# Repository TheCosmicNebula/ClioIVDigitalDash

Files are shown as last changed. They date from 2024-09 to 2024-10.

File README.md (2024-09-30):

 

# ClioIVDigitalDash
A place for me to store all my resources for my Renault Clio IV Digital Dash Project using RealDash, Raspberry Pi, Arduino and SocketCAN.

## License
All files are COPYRIGHT @ CGH Automotive Limited unless sourced from a Third Party, then the rights to those files are held with the relevant Third Party.

| 2023 - 2024 @ CGH Automotive Limited | TheCosmicNebula | All Rights Reserved (Except Where Specified) |

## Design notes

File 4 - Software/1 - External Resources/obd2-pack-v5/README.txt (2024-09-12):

Thanks for downloading our OBD2 data pack!

This pack contains the following:
1) Our OBD2 Intro & Data Logger articles in PDF form
2) Our OBD2 DBC file (for both 11-bit CAN IDs and 29-bit CAN IDs)
3) Various OBD2 sample log files - incl. an extensive one from a SEAT Leon
4) A collection of reverse-engineered DBC files, primarily from the opendbc github repo

You can open the MF4 log files e.g. in below software tools and use the OBD2 DBC to decode the data:

1) asammdf GUI: Good starting point for opening, DBC decoding and plotting the data
- Introduction: https://www.csselectronics.com/pages/asammdf-gui-api-mdf4-mf4

2) Python API: Automate the processing of the data
- Introduction: https://www.csselectronics.com/pages/python-can-bus-api

3) Grafana dashboards: Create custom dashboard visualizations of the data
- Introduction: https://www.csselectronics.com/pages/telematics-dashboard-open-source

4) MF4 converters: Ideal if you want to work with the log files in e.g. Vector/PEAK tools
- Introduction: https://www.csselectronics.com/pages/mdf4-converters-mf4-asc-csv

5) MF4 decoders: Easily DBC decode your data to CSV files or Parquet data lakes
- Introduction: https://www.csselectronics.com/pages/mdf4-decoders-dbc-mf4-parquet-csv

If any questions, feel free to contact us: https://www.csselectronics.com/pages/contact-us

best,
CSS Electronics

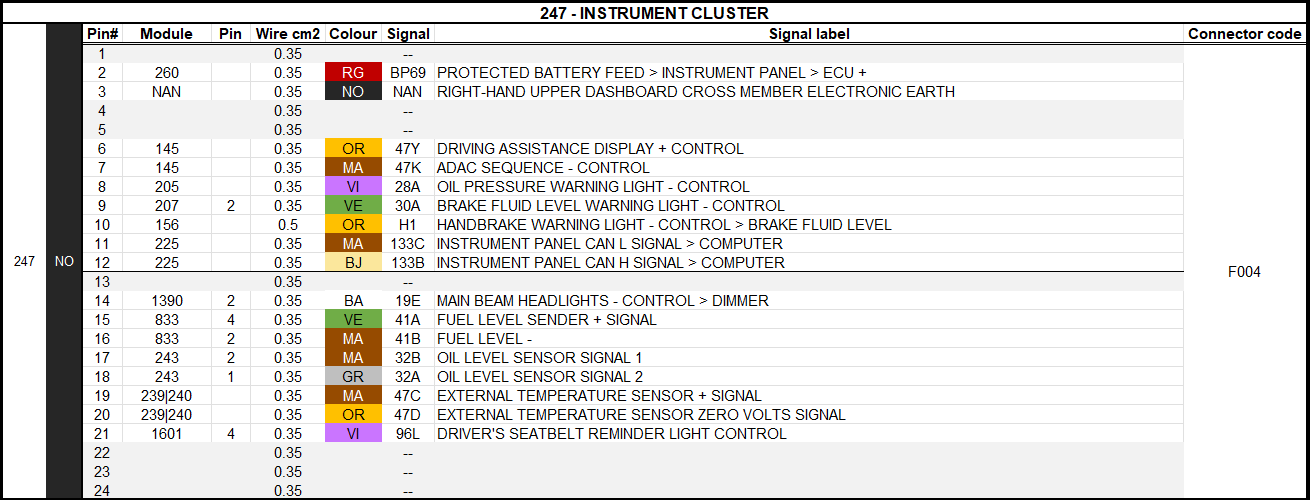
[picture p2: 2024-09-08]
1 - Physical Unit/2 - Connector/cluster_pinout_1.png

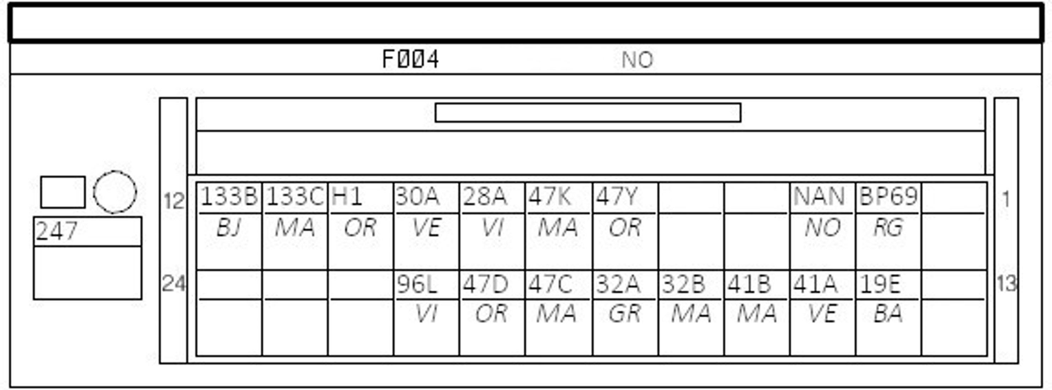
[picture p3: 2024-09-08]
1 - Physical Unit/2 - Connector/cluster_pinout.jpg

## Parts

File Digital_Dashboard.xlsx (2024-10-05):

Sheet: COST
 |  |  | £303.20 | £20.30 | £323.50
Item | Part # | Quantity | Cost | Delivery | Total | Status
10.4" QLED Quantum Dot Display |  | 1 | £104.10 | £9.99 | £114.09 | STORED
Raspberry Pi 5 |  | 1 | £52.00 |  | £52.00 | PROTOTYPE UNIT
RTC Battery for Raspberry Pi 5 |  | 1 | £4.90 | £10.31 | £15.21 | ORDERED
Waveshare RS485/CAN Hat |  | 1 | £16.99 |  | £16.99 | PROTOTYPE UNIT
Ardunio Nano Every |  | 1 | £13.95 |  | £13.95 | PROTOTYPE UNIT
12V to 5V 5A Buck Converter 2 pack |  | 1 | £6.97 |  | £6.97 | PROTOTYPE UNIT
Logitech K400 Plus Keyboard |  | 1 | £29.99 |  | £29.99 | PROTOTYPE UNIT
60mm 12V Cooling Fan |  | 1 | £4.86 |  | £4.86 | PROTOTYPE UNIT
OBD2 Connector Housing |  | 1 | £8.99 |  | £8.99 | PROTOTYPE UNIT
Copper Heatsinks for Raspberry Pi |  | 1 | £6.99 |  | £6.99 | PROTOTYPE UNIT
Single Channl 5V Relay Board x5 |  | 1 | £4.99 |  | £4.99 | PROTOTYPE UNIT
Right angle USB to Micro USB Cable |  | 1 | £3.00 |  | £3.00 | PROTOTYPE UNIT
Right angle USB to USB C cable |  | 1 | £6.99 |  | £6.99 | PROTOTYPE UNIT
USB C right angle extension |  | 1 | £7.49 |  | £7.49 | PROTOTYPE UNIT
Right angle HDMI to micro HDMI cable |  | 1 | £10.99 |  | £10.99 | PROTOTYPE UNIT
Shell |  | 1 | £20.00 |  | £20.00

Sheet: CLUSTER PINOUT
247 - INSTRUMENT CLUSTER
247 | NO | Pin# | Module | Pin | Size | Colour | Custom | Signal | Signal label
 |  | 1 |  |  | 0.35 |  |  | -- |  |  | F004
 |  | 2 | 260 |  | 0.35 | RG | RED | BP69 | PROTECTED BATTERY FEED > INSTRUMENT PANEL > ECU + | Power on all the time
 |  | 3 | NAN |  | 0.35 | NO | BLACK | NAN | RIGHT-HAND UPPER DASHBOARD CROSS MEMBER ELECTRONIC EARTH | Ground
 |  | 4 |  |  | 0.35 |  |  | --
 |  | 5 |  |  | 0.35 |  |  | --
 |  | 6 | 145 | 2 | 0.35 | OR | GREEN | 47Y | DRIVING ASSISTANCE DISPLAY + CONTROL | Stalk button upper, switch to ground
 |  | 7 | 145 | 3 | 0.35 | MA | BLUE | 47K | DRIVING ASSISTANCE DISPLAY - CONTROL | Stalk button lower, switch to ground
 |  | 8 | 205 |  | 0.35 | VI | YEL | 28A | OIL PRESSURE WARNING LIGHT - CONTROL | Ground NC - Low pressure = open circuit
 |  | 9 | 207 | 2 | 0.35 | VE | RED | 30A | BRAKE FLUID LEVEL WARNING LIGHT - CONTROL | Ground NO - Low brake fluid = closed circuit
 |  | 10 | 156 |  | 0.50 | OR | WHITE | H1 | HANDBRAKE WARNING LIGHT - CONTROL > BRAKE FLUID LEVEL | Ground NC - Handbrake on = closed circuit
 |  | 11 | 225 |  | 0.35 | MA | BLU | 133C | INSTRUMENT PANEL CAN L SIGNAL > COMPUTER | Main CANBus
 |  | 12 | 225 |  | 0.35 | BJ | YEL | 133B | INSTRUMENT PANEL CAN H SIGNAL > COMPUTER
 |  | 13 |  |  | 0.35 |  |  | --
 |  | 14 | 1390 | 2 | 0.35 | BA |  | 19E | MAIN BEAM HEADLIGHTS - CONTROL > DIMMER | Resistance based, brightness
 |  | 15 | 833 | 4 | 0.35 | VE | RED | 41A | FUEL LEVEL SENDER + SIGNAL | Resistance based
 |  | 16 | 833 | 2 | 0.35 | MA | GREEN | 41B | FUEL LEVEL -
 |  | 17 | 243 | 2 | 0.35 | MA |  | 32B | OIL LEVEL SENSOR SIGNAL - | Resistance based
 |  | 18 | 243 | 1 | 0.35 | GR |  | 32A | OIL LEVEL SENSOR SIGNAL +
 |  | 19 | 239|240 |  | 0.35 | MA | RED | 47C | EXTERNAL TEMPERATURE SENSOR + SIGNAL | Resistance based
 |  | 20 | 239|240 |  | 0.35 | OR | BLUE | 47D | EXTERNAL TEMPERATURE SENSOR ZERO VOLTS SIGNAL
 |  | 21 | 1601 | 4 | 0.35 | VI | WHITE | 96L | DRIVER'S SEATBELT REMINDER LIGHT CONTROL | Positive control
 |  | 22 |  |  | 0.35 |  |  | --
 |  | 23 |  |  | 0.35 |  |  | 133C | CAN L SIGNAL LOOP OUT
 |  | 24 |  |  | 0.35 |  |  | 133B | CAN H SIGNAL LOOP OUT

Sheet: PI PINOUT
Pinout |  |  |  |  |  | Pins needed |  |  | 13 | Function |  |  |  | 13
Used | Function | Pin |  | Function | Used | Function | Direction | Comments |  | Function | Pin | Used | Type |  | 3.3v
 | 3V3 Power | 1 | 2 | 5V Power |  | Oil Pressure Warning Light | IN | Via Arduino - Ground NC - Low pressure open circuit |  | 3V3 Power | 1 |  | 3.3v |  | 5v
 | GPIO 2 (SDA) | 3 | 4 | 5V Power |  | Brake Fluid Warning Light | IN | Via Arduino - Ground NO - Low brake fluid closed circuit |  | 5V Power | 2 |  | 5v |  | GND
 | GPIO 3 (SCL) | 5 | 6 | Ground |  | Handbrake Light | IN | Via Arduino - Ground NC - Handbrake on closed circuit |  | GPIO 2 (I2C_SDA) | 3 |  | I2C |  | I2C
CAN Hat | GPIO 4 (GPCLK0) | 7 | 8 | GPIO 14 (TXD) | CAN Hat | FUEL Level Sender + |  | Via Arduino |  | 5V Power | 4 |  | 5v |  | General
 | Ground | 9 | 10 | GPIO 15 (RXD) | CAN Hat | FUEL Level Sender - |  |  |  | GPIO 3 (I2C_SCL) | 5 |  | I2C |  | UART
FAN | GPIO 17 | 11 | 12 | GPIO 18 (PCM_CLK) |  | OIL Level Sender + |  | Via Arduino |  | Ground | 6 |  | GND |  | SPI
AIRBG | GPIO 27 | 13 | 14 | Ground |  | OIL Level Sender - |  |  |  | GPIO 4 (GPCLK0) | 7 | CAN Hat | General |  | PCM
 | GPIO 22 | 15 | 16 | GPIO 23 |  | External Temp + |  | Via Arduino |  | GPIO 14 (UART_TXD) | 8 | CAN Hat | UART
 | 3V3 Power | 17 | 18 | GPIO 24 |  | External Temp - |  |  |  | Ground | 9 |  | GND
CAN Hat | GPIO 10 (MOSI) | 19 | 20 | Ground |  | Stalk Button UP | IN | Via Arduino - Ground switched |  | GPIO 15 (UART_RXD) | 10 | CAN Hat | UART
CAN Hat | GPIO 9 (MISO) | 21 | 22 | GPIO 25 | CAN Hat | Stalk Button DOWN | IN | Via Arduino - Ground switched |  | GPIO 17 | 11 |  | General
CAN Hat | GPIO 11 (SCK) | 23 | 24 | GPIO 8 (CE0) | CAN Hat | Driver Airbag Light | OUT | Positive control |  | GPIO 18 (PCM_CLK) | 12 |  | PCM
 | Ground | 25 | 26 | GPIO 7 (CE1) |  | Onboard Fan Control | OUT | 5V Positive Controlled relay board |  | GPIO 27 | 13 |  | General
 | GPIO 0 (ID_SD) | 27 | 28 | GPIO 1 (ID_SC) |  |  |  |  |  | Ground | 14 |  | GND
 | GPIO 5 | 29 | 30 | Ground |  |  |  |  |  | GPIO 22 | 15 |  | General
 | GPIO 6 | 31 | 32 | GPIO 12 (PWM0) |  |  |  |  |  | GPIO 23 | 16 |  | General
 | GPIO 13 (PWM1) | 33 | 34 | Ground |  |  |  |  |  | 3V3 Power | 17 |  | 3.3v
 | GPIO 19 (PCM_FS) | 35 | 36 | GPIO 16 |  |  |  |  |  | GPIO 24 | 18 |  | General
 | GPIO 26 | 37 | 38 | GPIO 20 (PCM_DIN) |  |  |  |  |  | GPIO 10 (SPI0_MOSI) | 19 | CAN Hat | SPI
 | Ground | 39 | 40 | GPIO 21 (PDM_DOUT) |  |  |  |  |  | Ground | 20 |  | GND
 |  |  |  |  |  |  |  |  |  | GPIO 9 (SPI0_MISO) | 21 | CAN Hat | SPI
 |  |  |  |  |  | USB DEVICES |  |  |  | GPIO 25 | 22 | CAN Hat | General
 |  |  |  |  |  | USB 2.0 | LOGITECH KEYBOARD RECIEVER |  |  | GPIO 11 (SPI0_SCLK) | 23 | CAN Hat | SPI
 |  |  |  |  |  | USB 2.0 | GPS MODULE |  |  | GPIO 8 (CE0) | 24 | CAN Hat | SPI
 |  |  |  |  |  |  |  |  |  | Ground | 25 |  | GND
 |  |  |  |  |  | USB 3.0 | ARDUINO SERIAL CONNECTION |  |  | GPIO 7 (CE1) | 26 |  | SPI
 |  |  |  |  |  | USB 3.0 | WAVESHARE TOUCHSCREEN CONNECTION |  |  | GPIO 0 (EEPROM_SDA) | 27 |  | I2C
 |  |  |  |  |  |  |  |  |  | GPIO 1 (EEPROM_SCL) | 28 |  | I2C
 |  |  |  |  |  |  |  |  |  | GPIO 5 | 29 |  | General
 |  |  |  |  |  |  |  |  |  | Ground | 30 |  | GND
 |  |  |  |  |  |  |  |  |  | GPIO 6 | 31 |  | General
 |  |  |  |  |  |  |  |  |  | GPIO 12 (PWM0) | 32 |  | General
 |  |  |  |  |  |  |  |  |  | GPIO 13 (PWM1) | 33 |  | General
 |  |  |  |  |  |  |  |  |  | Ground | 34 |  | GND
 |  |  |  |  |  |  |  |  |  | GPIO 19 (PCM_FS) | 35 |  | PCM
 |  |  |  |  |  |  |  |  |  | GPIO 16 | 36 |  | General
 |  |  |  |  |  |  |  |  |  | GPIO 26 | 37 |  | General
 |  |  |  |  |  |  |  |  |  | GPIO 20 (PCM_DIN) | 38 |  | PCM
 |  |  |  |  |  |  |  |  |  | Ground | 39 |  | GND
 |  |  |  |  |  |  |  |  |  | GPIO 21 (PDM_DOUT) | 40 |  | PCM

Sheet: ARDUINO PINOUT
Pinout |  |  |  |  |  |  |  | Pins needed
Used |  |  |  | Pin |  |  | Used | Function | DIR | Comments
LED_BUILTIN |  |  |  | D13 | D12 | INT_PULLUP | STALK+ | Oil Pressure Warning Light | IN | Ground NC - Normal pressure grounded, Low Pressure 5V
 |  |  |  | 3V3 | D11 | INT_PULLUP | STALK- | Brake Fluid Warning Light | IN | Ground NO - Low brake fluid gounded
 |  |  |  | AREF | D10 |  | PWM | Handbrake Light | IN | Ground NC - Handbrake activated grounded
DIMMER | DIVIDER | 14.5V -> 5V | A0 | D14 | D9 |  | PWM | FUEL Level Sender + | PWR | 5V Supply with 2K Voltage Divider
FUEL LEVEL | DIVIDER 2K | 5V | A1 | D15 | D8 | INT_PULLUP | OIL PRESS | FUEL Level Sender - | IN
EXT TEMP | DIVIDER 2K | 5V | A2 | D16 | D7 | INT_PULLUP | BRAKE FLUID | OIL Level Sender + | PWR | 5V Supply with 2K Voltage Divider
OIL LEVEL | DIVIDER 2K | 5V | A3 | D17 | D6 |  | PWM | OIL Level Sender - | IN
 |  |  | A4 | D18 | D5 |  | PWM | External Temp + | PWR | 5V Supply with 2K Voltage Divider
 |  |  | A5 | D19 | D4 | INT_PULLUP | HANDBRAKE | External Temp - | IN
 |  |  | A6 | D20 | D3 |  | PWM | Stalk Button UP | IN | Grounded when pressed
 |  |  | A7 | D21 | D2 |  |  | Stalk Button DOWN | IN | Grounded when pressed
 |  |  |  | +5V | GND |  |  | DIMMER | IN | 12 - 15V assumed variable voltage
 |  |  |  | RST | RST
 |  |  |  | GND | TX
7 - 21V |  | 7 - 21V |  | VIN | RX
2K divider needs verifying that 2K is suitable
DIMMER is 12v (14.5)v LPE or Internal Lighting Activated with a Variable Potentiometer
Measure resistance and use minimum and maximum to determine suitable voltage divider setup
 |  |  |  |  | 1 | OIL SIG
 |  |  |  |  | 2 | OIL +
 |  |  |  |  | 3 | TEMP SIG
 |  |  |  |  | 4 | TEMP +
 |  |  |  |  | 5 | FUEL SIG
 |  |  |  |  | 6 | FUEL +

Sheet: FUNCTIONS
 |  |  |  |  |  |  | -
Function List (Not Exhaustive) |  |  |  |  |  |  | ✔
No | Function | Desc | OBD2 | CanBUS | NANO | CanAddress | ✖
 | Cluster Lights
1 | Left Indicator |  |  | ✔
2 | Right Indicator |  |  | ✔ |  |  |  | CAN Wake Up Signal
3 | Hazard Indicators |  |  | ✔ |  |  |  | CAN Sleep Signal
4 | Battery Warning |  |  |  |  |  |  | OR
5 | Main Beam |  |  | ✔ |  |  |  | Use accessory power for wake, or other protected power source that is on before accessory and after accessory, but does not drain battery
6 | Low Beam |  |  | ✔
7 | Side Lights |  |  | ✔
8 | Cruise Control |  |  | ✔
9 | Speed Limiter |  |  | ✔ |  |  |  | Turn off Pi boot screen | in | /boot/firmware/config.txt
10 | Handbrake ON |  |  | - | ✔ | Arduino Nano via CAN |  |  |  | + disable_splash=1
11 | ESC Off |  |  | ✔ |  |  |  |  |  | +logo.nologo
12 | STOP |  |  |  |  |  |  |  |  | +consoleblank=0
13 | Door Open |  |  | ✔ |  |  |  |  |  | +loglevel=1 quiet | didnt work
14 | OSF Door Open |  |  | ✔
15 | NSF Door Open |  |  | ✔
16 | OSR Door Open |  |  | ✔
17 | NSR Door Open |  |  | ✔
18 | Boot Open |  |  | ✔
19 | SPANNER
20 | Temp Low |  |  | ✔
21 | Temp High |  |  | ✔ |  |  |  | /home/pi/startup.py |  | Fan on + drivers airbag light for 1 minute
22 | Oil Warning |  |  | - | ✔ | Arduino Nano via CAN |  | /home/pi/stop_fan.py
23 | Fuel Low |  |  | - | ✔ | Arduino Nano via CAN
24 | Tyre Pressure
25 | ABS |  |  | ✔
26 | Front Fog |  |  | ✔
27 | Rear Fog |  |  | ✔
28 | Check Engine |  |  | ✔
29 | Airbag |  |  | ✔
30 | Renaultsport |  |  | ✔
 | Cluster Messages
1 | PARKING BRAKE ON |  |  | ✔
2 | PLEASE REMOVE KEYCARD
3 | TRACTION CONTROL OFF
4 | ESC OFF |  |  | ✔
5 | TURN STEERINGWHEEL + START
6 | STEERING WHEEL NOT LOCKED
7 | CHECK VEHICLE
8 | CHECK AIRBAG
9 | CHECK ANTI-POLLUTION SYSTEM
10 | CHECK HILL START ASSIST
11 | ENGINE FAILURE HAZARD
12 | BRAKING SYSTEM FAULT
13 | BATTERY CHARGING FAULT
14 | PUNCTURE
15 | LAUNCH CONTROL
16
17
 | Cluster Info
1 | Speed |  | ✖ | ✔
2 | Rpm |  | ✔ | ✔
3 | Fuel Level |  | ✖ | - | ✔ | Arduino Nano via CAN
4 | Handbrake |  | ✔ | - | ✔ | Arduino Nano via CAN | CanBUS is transmitted by OEM cluster so this will be lost when full swap is done
5 | Current Gear |  | ✖ | ✔
6 | Auto / Manual |  | ✖ | ✔
7 | Gear Change Up |  | ✖
8 | Gear Change Down |  | ✖
9 | SPORT Mode |  | ✔ | ✔
10 | RACE Mode |  | ✔ | ✔
11 | Oil Level Warning |  | ✖ | - | ✔ | Arduino Nano via CAN
12 | Oil Pressure Warning |  | ✖ | - | ✔ | Arduino Nano via CAN
13 | External Temperature |  | ✖ | - | ✔ | Arduino Nano via CAN
14 | Mileage / Odometer |  | ✖ | ✔
15 | Battery Voltage
 | front right belt
 | front left belt
 | rear right belt
 | rear centre belt
 | rear left belt
 | Airbag Light
 | passenger seat detection
 | parking sensor info
 | gear up indicator
 | gear down indicator
 | check 666 for traction control |  | 666
 | boot |  | 5DE
 | Traction control off
 | key in slot
 | windows up / down
 | interior light?

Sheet: REALDASH
Function | Type | Number | Units
AFR 1 |  | 0 | C
AFR 2 |  | 1 | F
AFR Target 1 |  | 2 | K
AFR Target 2 |  | 3 | km/h
Accel Enrich |  | 4 | mph
Barometric Correction |  | 10 | bar
Barometric Pressure |  | 11 | psi
Battery Voltage |  | 12 | time
Boost Target (kPa) |  | 270 | bit
Check Engine Light | ON/OFF | 65
Cold Advance |  | 13
Coolant Temperature | Celsius | 14
EGO Correction 1 |  | 17
EGO Correction 2 |  | 18
EGT1 | Celsius | 106
EGT10 | Celsius | 115
EGT11 | Celsius | 116
EGT12 | Celsius | 117
EGT2 | Celsius | 107
EGT3 | Celsius | 108
EGT4 | Celsius | 109
EGT5 | Celsius | 110
EGT6 | Celsius | 111
EGT7 | Celsius | 112
EGT8 | Celsius | 113
EGT9 | Celsius | 114
Engine Oil Pressure | Bar | 151
Engine Oil Temperature | Celsius | 152
Engine Runtime (sec) |  | 33
Enginebit: Antiflood | ON/OFF | 393
Enginebit: Closed Loop Active | ON/OFF | 395
Enginebit: Cranking | ON/OFF | 57
Enginebit: Fuel Cut Active |  | 406
Enginebit: Idle | ON/OFF | 396
Enginebit: Launch Control | ON/OFF | 394
Enginebit: MAP accel active | ON/OFF | 62
Enginebit: MAP deaccel active | ON/OFF | 63
Enginebit: Overrun | ON/OFF | 397
Enginebit: Running | ON/OFF | 56
Enginebit: Startup Enrich | ON/OFF | 58
Enginebit: TPS accel active | ON/OFF | 60
Enginebit: TPS deaccel active | ON/OFF | 61
Enginebit: Warmup | ON/OFF | 59
Flex Fuel Correction |  | 20
Fuel Pressure | Bar | 202
Fuel Temperature | Celsius | 499
Fuel flow |  | 490
Ignition Dwell |  | 26
Intake Air Temperature | Celsius | 27
Knock Advance Retard |  | 28
Knock Percentage |  | 29
Lambda 1 |  | 254
Lambda 2 |  | 255
Lambda Target 1 |  | 256
Lambda Target 2 |  | 257
MAF g/s |  | 30
Manifold Absolute Pressure |  | 31
Manifold Absolute Pressure dot |  | 32
Number of CEL codes |  | 66
OBD2: Engine Load |  | 100
OBD2: Long Term Fuel Trim, Bank 1 |  | 102
OBD2: Long Term Fuel Trim, Bank 2 |  | 104
OBD2: Short Term Fuel Trim, Bank 1 |  | 101
OBD2: Short Term Fuel Trim, Bank 2 |  | 103
Pulse Width 1 |  | 35
Pulse Width 2 |  | 36
RPM |  | 37
Rotating Error Code |  | 105
Spark Advance |  | 38
TPS dot |  | 41
Throttle Position |  | 41
Total Fuel Correction |  | 43
VSS1 | KPH | 81
VSS2 | KPH | 99
VVT, Exhaust Cam Position 1 |  | 493
VVT, Exhaust Cam Position 2 |  | 495
VVT, Exhaust Cam Target Position |  | 497
VVT, Intake Cam Position 1 |  | 492
VVT, Intake Cam Position 2 |  | 494
VVT, Intake Cam Target Position |  | 496
Vehicle Max Speed | KPH | 408
Vehicle Speed | KPH | 64
2nd Gear Start indicator (Transmission) | ON/OFF | 148
4WD Active | ON/OFF | 149
4WD Low Range Active | ON/OFF | 150
Downshift indicator (Transmission) | ON/OFF | 145
Gear (Transmission) |  | 139
Lockup Active (Transmission) | ON/OFF | 143
Low Range indicator (Transmission) | ON/OFF | 146
Oil Temperature (Transmission) | ON/OFF | 138
Overdrive indicator (Transmission) | ON/OFF | 147
Selected Gear (Transmission) |  | 140
Shifter Position (Transmission) |  | 141
Throttle Position (Transmission) |  | 137
Tuning Map (Transmission) |  | 142
Upshift indicator (Transmission) | ON/OFF | 144
Vehicle Speed (Transmission) | KPH | 136
ABS Warning |  | 273
AC Active |  | 335
AC Set Temperature (Zone 1) |  | 175
AC Set Temperature (Zone 2) |  | 312
AC Set Temperature (Zone 3) |  | 313
AC Set Temperature (Zone 4) |  | 314
Air Flow Defrost Active (Zone 1) | ON/OFF | 315
Air Flow Defrost Active (Zone 2) | ON/OFF | 318
Air Flow Defrost Active (Zone 3) | ON/OFF | 321
Air Flow Defrost Active (Zone 4) | ON/OFF | 324
Air Flow Face Active (Zone 1) | ON/OFF | 317
Air Flow Face Active (Zone 2) | ON/OFF | 320
Air Flow Face Active (Zone 3) | ON/OFF | 323
Air Flow Face Active (Zone 4) | ON/OFF | 326
Air Flow Feet Active (Zone 1) | ON/OFF | 316
Air Flow Feet Active (Zone 2) | ON/OFF | 319
Air Flow Feet Active (Zone 3) | ON/OFF | 322
Air Flow Feet Active (Zone 4) | ON/OFF | 325
Air Recirculation Active | ON/OFF | 336
Airbag Warning | ON/OFF | 272
Ambient Temperature | Celsius | 173
Brake Fluid Level |  | 178
Brake LF temperature | Celsius | 244
Brake LR temperature | Celsius | 246
Brake RF temperature | Celsius | 245
Brake RR temperature | Celsius | 247
Brake pedal position |  | 230
Clutch pedal position |  | 231
Coolant Level |  | 177
Cruise Control Accelerate | ON/OFF | 735
Cruise Control Active | ON/OFF | 169
Cruise Control Autospeed Active | ON/OFF | 737
Cruise Control Decelerate | ON/OFF | 736
Cruise Control Set Value | KPH | 171
Distance to ObstacleKilometers | Kilometers | 354
Door 1 Open | ON/OFF | 481
Door 2 Open | ON/OFF | 482
Door 3 Open | ON/OFF | 483
Door 4 Open | ON/OFF | 484
Door 5 Open | ON/OFF | 485
Door 6 Open | ON/OFF | 486
Door Ajar | ON/OFF | 162
EV: Battery Charge Time |  | 341
EV: Battery Charge Time Remaining |  | 342
EV: Battery Level 1 |  | 478
EV: Battery Level 2 |  | 479
EV: Battery Voltage |  | 339
EV: Charge Voltage |  | 340
EV: Energy Consumption (W/hr) |  | 337
EV: Energy Consumption Average (Wh/distance) |  | 338
Engine Cooling Fan | ON/OFF | 153
Engine Oil Level |  | 180
Front Fog Lights | ON/OFF | 392
Fuel Level |  | 170
Fuel Pump 1 | ON/OFF | 182
Fuel Pump 2 | ON/OFF | 183
Fuel Pump 3 | ON/OFF | 184
Fuel Pump 4 | ON/OFF | 185
Gear |  | 200
Hazard Switch | ON/OFF | 166
Heater Motor Level |  | 172
High Beam | ON/OFF | 157
Hood Open | ON/OFF | 487
Horn | ON/OFF | 165
Ignition On | ON/OFF | 167
Inside Temperature |  | 174
Instrument Panel Lights | ON/OFF | 186
Interior Lights | ON/OFF | 187
Low Beam | ON/OFF | 156
Neutral Safety Switch | ON/OFF | 489
Odometer | Kilometers | 310
Parking Brake | ON/OFF | 164
Parking Lights | ON/OFF | 155
Rear Fog Lights | ON/OFF | 158
Reverse Lights | ON/OFF | 159
Seat Belt Warning | ON/OFF | 168
Seat Cooler (Zone 1) |  | 331
Seat Cooler (Zone 2) |  | 332
Seat Cooler (Zone 3) |  | 333
Seat Cooler (Zone 4) |  | 334
Seat Heater (Zone 1) |  | 327
Seat Heater (Zone 2) |  | 328
Seat Heater (Zone 3) |  | 329
Seat Heater (Zone 4) |  | 330
Starter Motor | ON/OFF | 154
Steering Wheel 1 | ON/OFF | 188
Steering Wheel 2 | ON/OFF | 189
Steering Wheel 3 | ON/OFF | 190
Steering Wheel 4 | ON/OFF | 191
Steering Wheel 5 | ON/OFF | 192
Steering Wheel 6 | ON/OFF | 193
Steering Wheel Angle (degrees) |  | 229
Steering Wheel DPAD Back | ON/OFF | 199
Steering Wheel DPAD Down | ON/OFF | 197
Steering Wheel DPAD Left | ON/OFF | 194
Steering Wheel DPAD OK | ON/OFF | 198
Steering Wheel DPAD Right | ON/OFF | 196
Steering Wheel DPAD Up | ON/OFF | 195
Traction Control Percentage |  | 179
Tripmeter A | Kilometers | 311
Tripmeter B | Kilometers | 356
Trunk Ajar | ON/OFF | 163
Turn Signal Left | ON/OFF | 160
Turn Signal Right | ON/OFF | 161
Tyre Front Left Battery Low | ON/OFF | 743
Tyre Front Left Leaking | ON/OFF | 739
Tyre Front Left Pressure | Bar | 240
Tyre Front Left Sensor Connected | ON/OFF | 747
Tyre Front Left Temperature | Celsius | 232
Tyre Front Left Wear |  | 236
Tyre Front Right Battery Low | ON/OFF | 744
Tyre Front Right Leaking | ON/OFF | 740
Tyre Front Right Pressure | Bar | 241
Tyre Front Right Sensor Connected | ON/OFF | 748
Tyre Front Right Temperature | Celsius | 233
Tyre Front Right Wear |  | 237
Tyre Rear Left Battery Low | ON/OFF | 745
Tyre Rear Left Leaking | ON/OFF | 741
Tyre Rear Left Pressure | Bar | 242
Tyre Rear Left Sensor Connected | ON/OFF | 479
Tyre Rear Left Temperature | Celsius | 234
Tyre Rear Left Wear |  | 238
Tyre Rear Right Battery Low | ON/OFF | 746
Tyre Rear Right Leaking | ON/OFF | 742
Tyre Rear Right Pressure | Bar | 243
Tyre Rear Right Sensor Connected | ON/OFF | 758
Tyre Rear Right Temperature | Celsius | 235
Tyre Rear Right Wear |  | 239
Washer Fluid Level |  | 176
Windshield Washer Active | ON/OFF | 181
Acceleration (ABS) |  | 5
Acceleration X |  | 6
Acceleration X (RAW) |  | 264
Acceleration Y |  | 7
Acceleration Y (RAW) |  | 265
Acceleration Z |  | 8
Acceleration Z (RAW) |  | 266
Audio Volume |  | 275
Battery Charging | ON/OFF | 343
Battery Level |  | 253
Bluetooth Active |  | 276
Connected Device Count |  | 365
Date | Text | 211
GPS AltitudeMeters | Meters | 21
GPS Connected | ON/OFF | 252
GPS Date | Text | 358
GPS Heading |  | 209
GPS Latitude |  | 22
GPS Longitude |  | 23
GPS Speed | KPH | 24
GPS Time | Text | 357
Heart Rate |  | 250
Keyboard Status |  | 498
Navigation: Active | ON/OFF | 344
Navigation: Distance to Destination | Kilometers | 346
Navigation: Distance to next Waypoint | Kilometers | 347
Navigation: ETA | Text | 350
Navigation: Instruction, Current | Text | 348
Navigation: Instruction, Next | Text | 349
Navigation: Maneuver, Current | Text | 351
Navigation: Maneuver, Next 1 | Text | 352
Navigation: Maneuver, Next 2 | Text | 353
Navigation: Time to Destination |  | 345
Night Mode |  | 309
Screen Brightness |  | 274
Screen Capture Active | ON/OFF | 491
System Notification | Text | 248
Time (ISO 8601) | Text | 118
Time (Local) | Text | 210
Weekday | Text | 359
WiFi Active |  | 277
App ShutdownOn/Off87 | ON/OFF | 87
App Started |  | 86
Color Brightness Slider |  | 376
Color Slider 1 |  | 366
Color Slider 2 |  | 367
Color Slider 3 |  | 368
Color Slider 4 |  | 369
Current Dash Page |  | 404
Currently Playing Album | Text | 89
Currently Playing Artist | Text | 88
Currently Playing Duration |  | 278
Currently Playing Folder | Text | 488
Currently Playing Position |  | 279
Currently Playing Title | Text | 90
Dummy 01 |  | 93
Dummy 02 |  | 94
Dummy 03 |  | 95
Dummy 04 |  | 96
Dummy 05 |  | 97
Dummy 06 |  | 121
Dummy 07 |  | 122
Dummy 08 |  | 123
Dummy 09 |  | 124
Dummy 10 |  | 125
Dummy 11 |  | 126
Dummy 12 |  | 127
Dummy 13 |  | 128
Dummy 14 |  | 129
Dummy 15 |  | 130
Dummy 16 |  | 131
Dummy 17 |  | 132
Dummy 18 |  | 133
Dummy 19 |  | 134
Dummy 20 |  | 135
Dummy 21 |  | 281
Dummy 22 |  | 282
Dummy 23 |  | 283
Dummy 24 |  | 284
Dummy 25 |  | 285
Dummy 26 |  | 286
Dummy 27 |  | 287
Dummy 28 |  | 288
Dummy 29 |  | 289
Dummy 30 |  | 290
Dummy 31 |  | 291
Dummy 32 |  | 292
Dummy 33 |  | 293
Dummy 34 |  | 294
Dummy 35 |  | 295
Dummy 36 |  | 296
Dummy 37 |  | 297
Dummy 38 |  | 298
Dummy 39 |  | 299
Dummy 40 |  | 301
Dummy timer 01 |  | 34
Dummy timer 02 |  | 47
Dummy timer 03 |  | 48
Dummy timer 04 |  | 49
Dummy timer 05 |  | 98
Dummy timer 06 |  | 302
Dummy timer 07 |  | 303
Dummy timer 08 |  | 304
Dummy timer 09 |  | 305
Dummy timer 10 |  | 306
Heading as text | Text | 362
Map Center Latitude |  | 307
Map Center Longitude |  | 308
Map Zoom Level |  | 280
RealDash language codeText361 | Text | 361
Song Playing |  | 360
Song playback shuffle active |  | 405
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

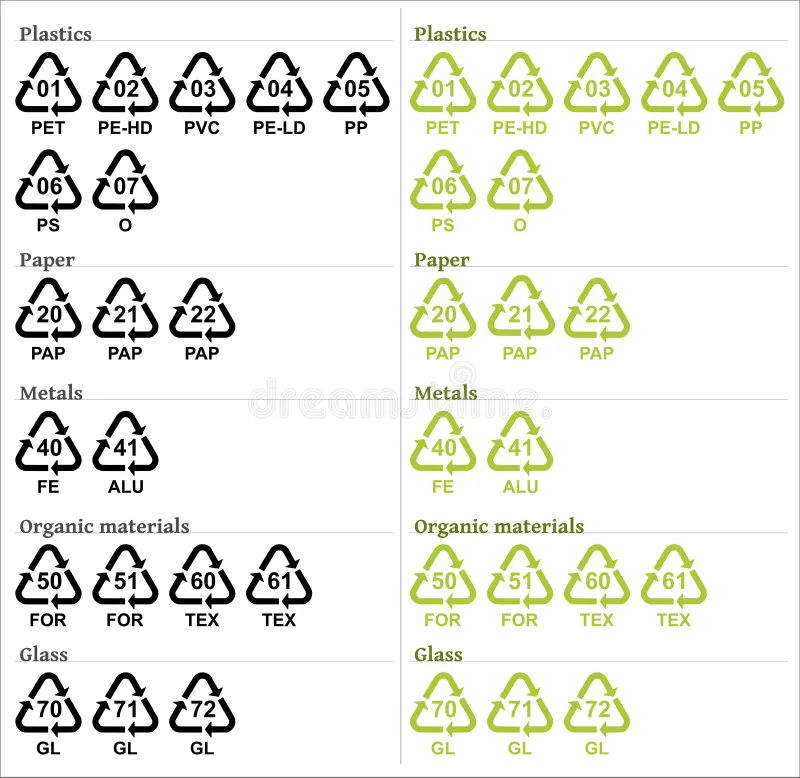
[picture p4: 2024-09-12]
1 - Physical Unit/3 - Label/components/recycle-symbols-codes-23069352.webp

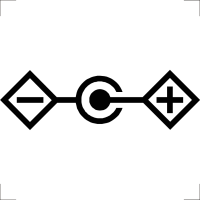
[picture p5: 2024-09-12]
1 - Physical Unit/3 - Label/components/polarity.png

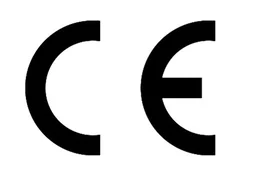
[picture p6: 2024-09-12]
1 - Physical Unit/3 - Label/components/CE-mark.webp

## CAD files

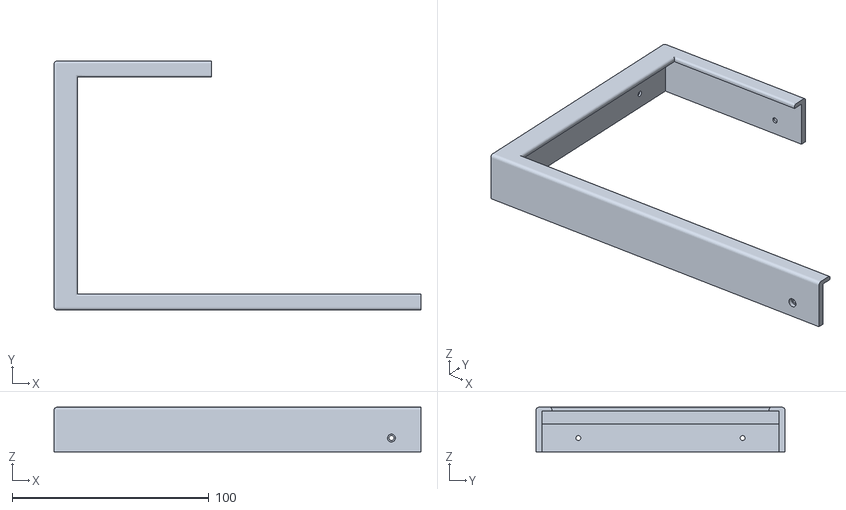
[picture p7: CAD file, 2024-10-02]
1 - Physical Unit/0 - Casing/bezel_left_v4.stl
186.3 x 126.4 x 22.7

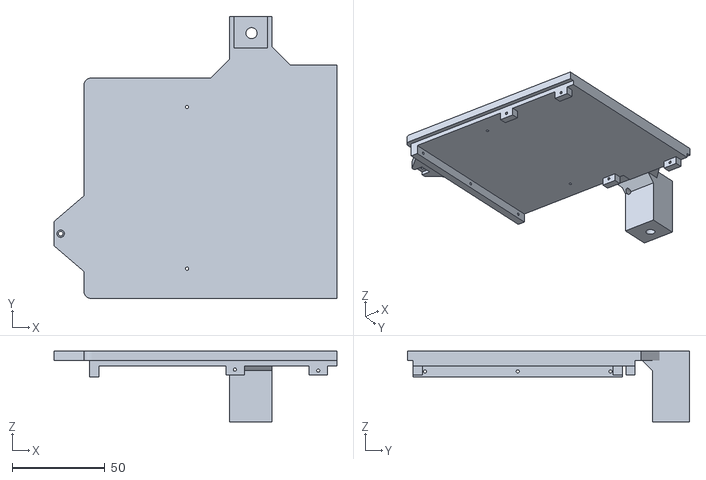
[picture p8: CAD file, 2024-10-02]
1 - Physical Unit/0 - Casing/ss/plate_left_v12.stl
152.5 x 152.2 x 38.2

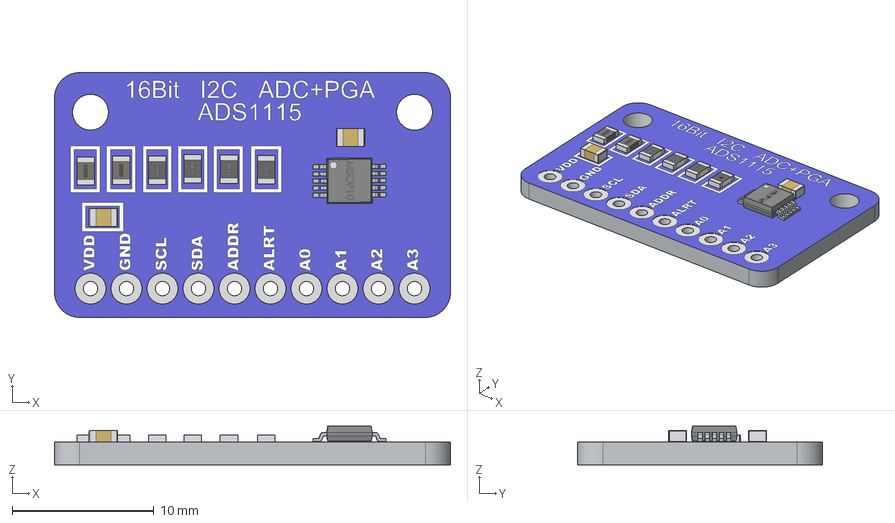
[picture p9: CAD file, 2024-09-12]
1 - Physical Unit/1 - Pi/ADCs/16Bit I2C ADC+PGA - ADS1115.stp
27.9 x 17.3 x 2.74 mm
ADS1115
0805 Capacitor x 2
0805 Inductor x 2
0805 Resistor x 4
MSOP10

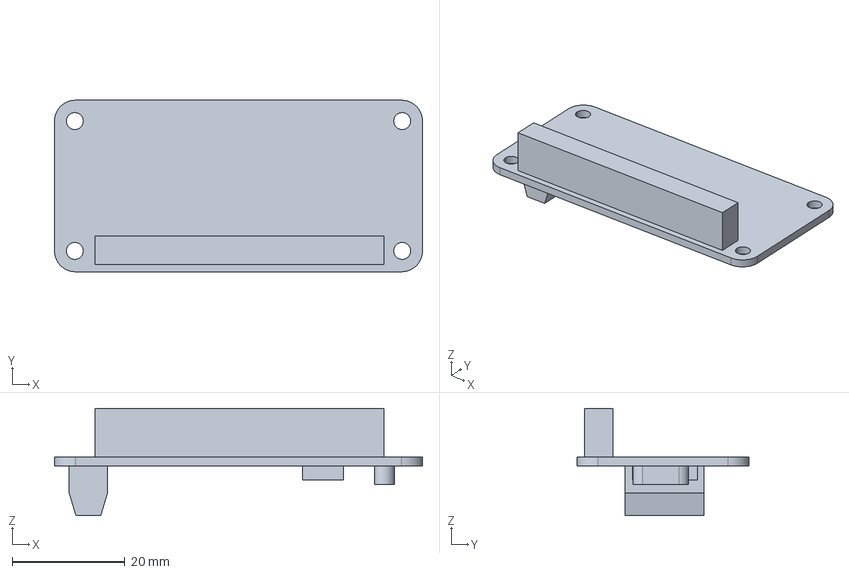
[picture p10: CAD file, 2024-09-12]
1 - Physical Unit/1 - Pi/CAN_Hat/t19-3.stp
65.2 x 30.4 x 19.0 mm

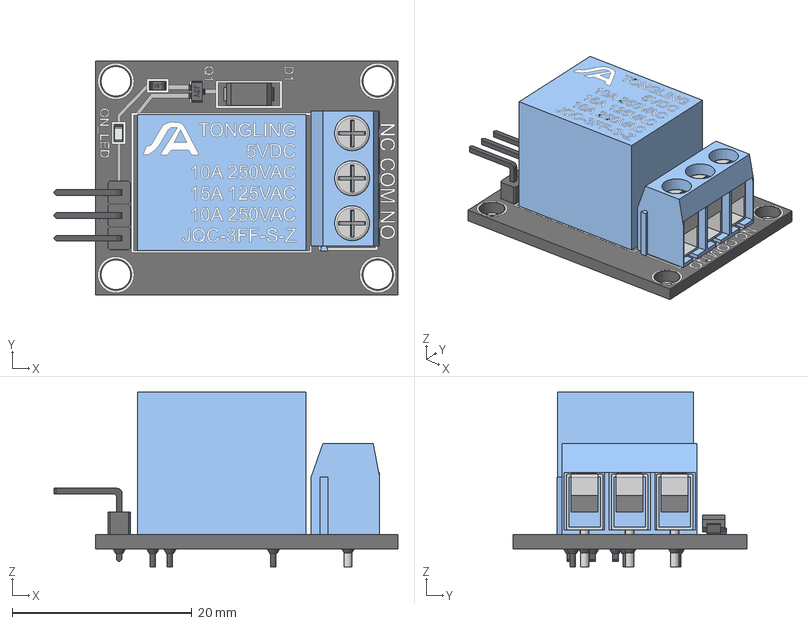
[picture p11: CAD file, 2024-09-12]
1 - Physical Unit/1 - Pi/Relay Board/5V KY-019 v95.step
38.2 x 26.0 x 19.4 mm
Tornillo M3X15 x 3
Pin_interno x 3
Punto se soldadura x 11
Relevador 5VDC
Diodo M7
LED VERDE SMD
RESISTENCIA 151
Transistor
Header_Body x 3
Pin x 3

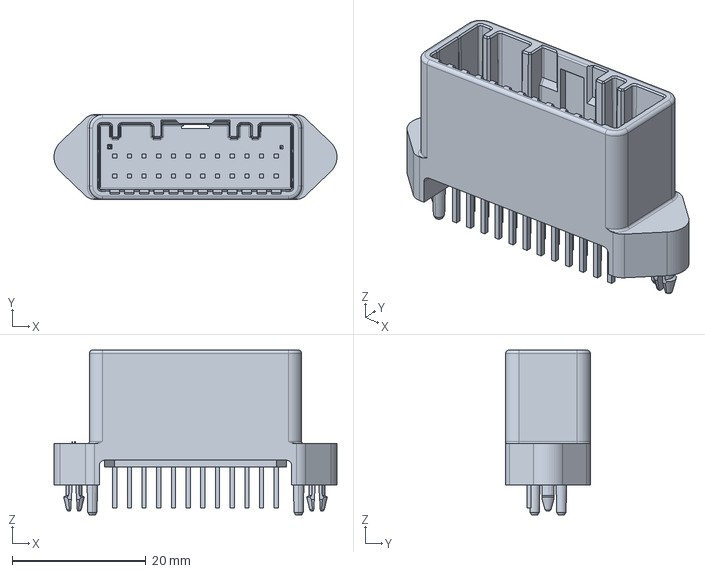
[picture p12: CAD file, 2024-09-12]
1 - Physical Unit/2 - Connector/1802828-1/c-1802828-1-a-3d.stp
42.4 x 12.7 x 24.7 mm

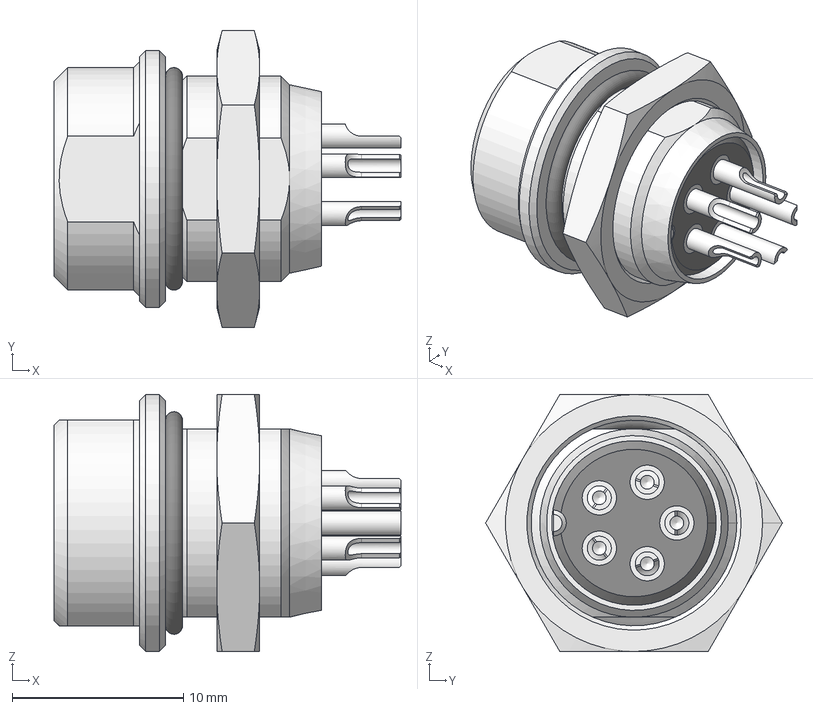
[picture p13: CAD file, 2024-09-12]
1 - Physical Unit/9 - Prototype/components/GX12-5 Jack.step
20.2 x 17.3 x 15.0 mm

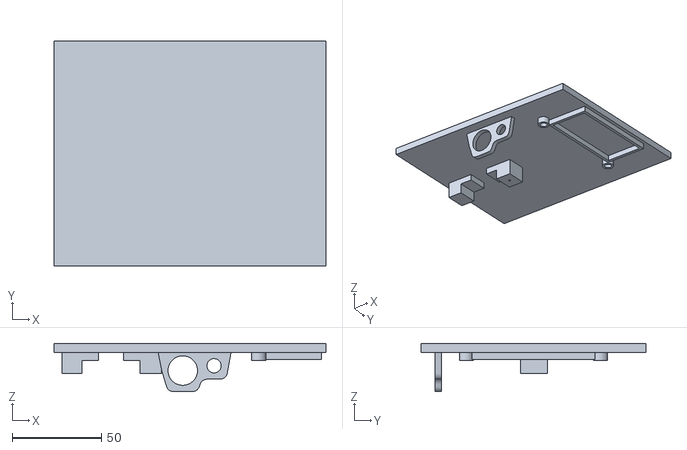
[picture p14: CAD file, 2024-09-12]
1 - Physical Unit/9 - Prototype/rear_plate_left_v2.stl
152.0 x 126.0 x 26.9

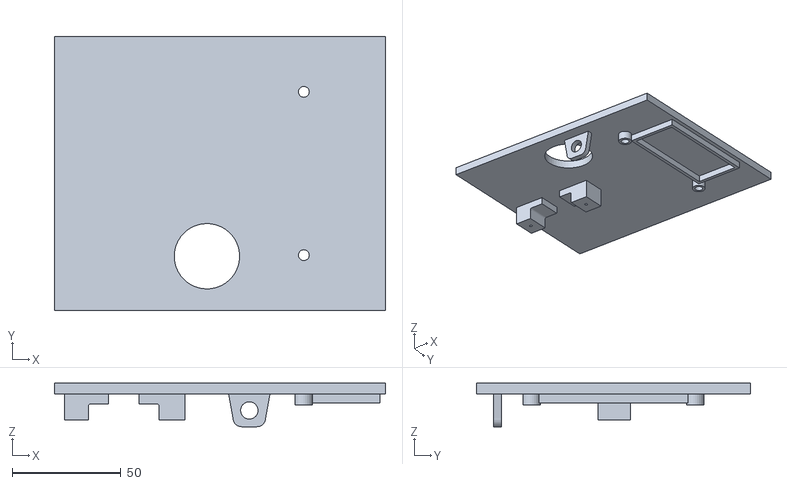
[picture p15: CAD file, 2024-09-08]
1 - Physical Unit/9 - Prototype/ss/rear_plate_left_v1.stl
152.0 x 126.0 x 20.0

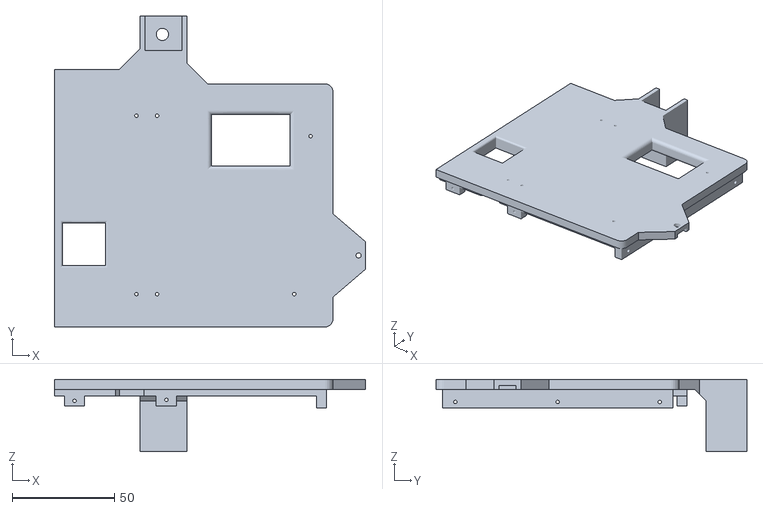
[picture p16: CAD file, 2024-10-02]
1 - Physical Unit/0 - Casing/plate_right_v14.stl
152.4 x 152.2 x 35.2

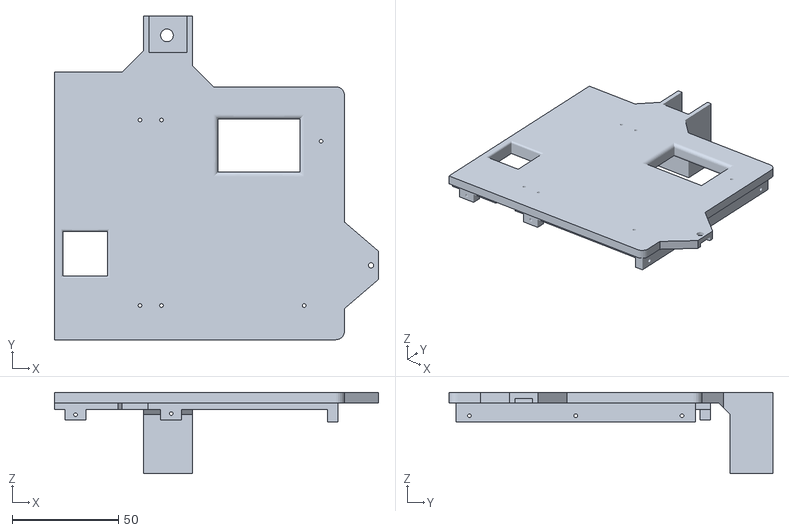
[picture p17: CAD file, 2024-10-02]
1 - Physical Unit/0 - Casing/ss/plate_right_v13.stl
152.4 x 152.2 x 38.2

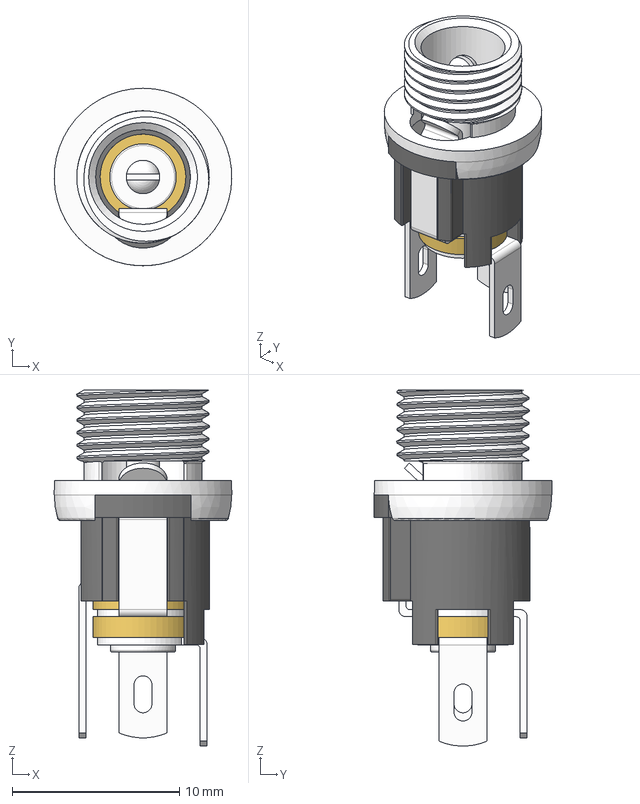
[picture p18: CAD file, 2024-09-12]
1 - Physical Unit/9 - Prototype/components/panel mount 5.5 x 2.1mm barrel plug.step
10.6 x 10.6 x 21.3 mm
Casing
insulators
Positive Center
Negative parts

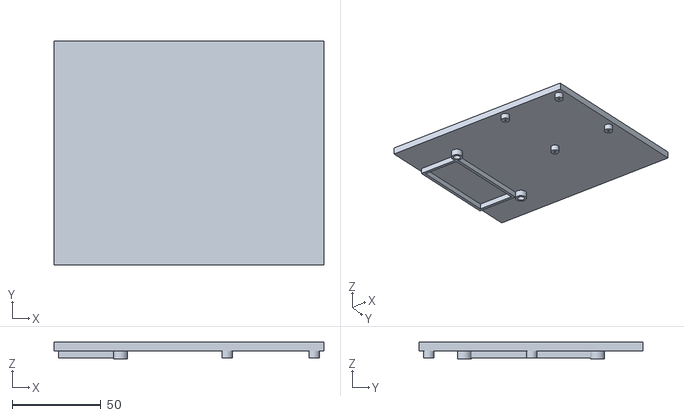
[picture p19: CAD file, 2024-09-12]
1 - Physical Unit/9 - Prototype/rear_plate_right_v2.stl
152.0 x 126.0 x 9.50

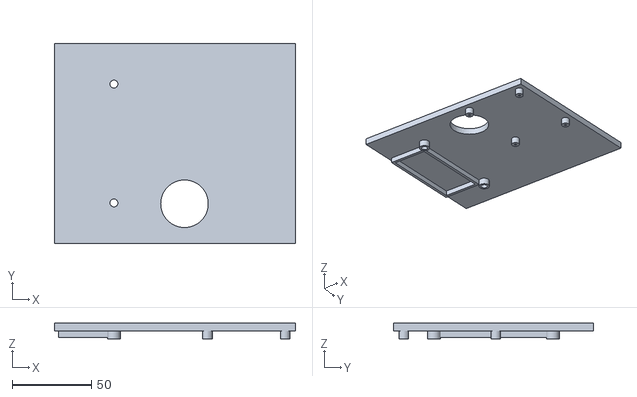
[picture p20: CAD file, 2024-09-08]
1 - Physical Unit/9 - Prototype/ss/rear_plate_right_v1.stl
152.0 x 126.0 x 10.0

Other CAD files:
1 - Physical Unit/0 - Casing/bezel_right_v4.stl
1 - Physical Unit/0 - Casing/ss/temp_bezel_left_1.stl
1 - Physical Unit/9 - Prototype/connector_clamp.stl
1 - Physical Unit/9 - Prototype/ss/rear_plate_v1.stl
1 - Physical Unit/0 - Casing/back_cover_left_v4.stl
1 - Physical Unit/0 - Casing/back_cover_right_v4.stl
1 - Physical Unit/0 - Casing/connector_retention_v4.stl
1 - Physical Unit/0 - Casing/fan_duct_v3.stl
1 - Physical Unit/0 - Casing/frame_clamp_v1.stl
1 - Physical Unit/0 - Casing/frame_left_v1.stl
1 - Physical Unit/0 - Casing/frame_right_bottom_v1.stl
1 - Physical Unit/0 - Casing/frame_right_top_v1.stl
1 - Physical Unit/0 - Casing/pin_v2.stl
1 - Physical Unit/0 - Casing/plate_left_v14.stl
1 - Physical Unit/0 - Casing/rear_shell_left_v9.stl
1 - Physical Unit/0 - Casing/rear_shell_right_v9.stl
1 - Physical Unit/0 - Casing/ss/back_cover_left_v1.stl
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

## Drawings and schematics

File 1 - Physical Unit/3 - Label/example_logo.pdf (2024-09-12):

109.6+/-0.1
3 | 3

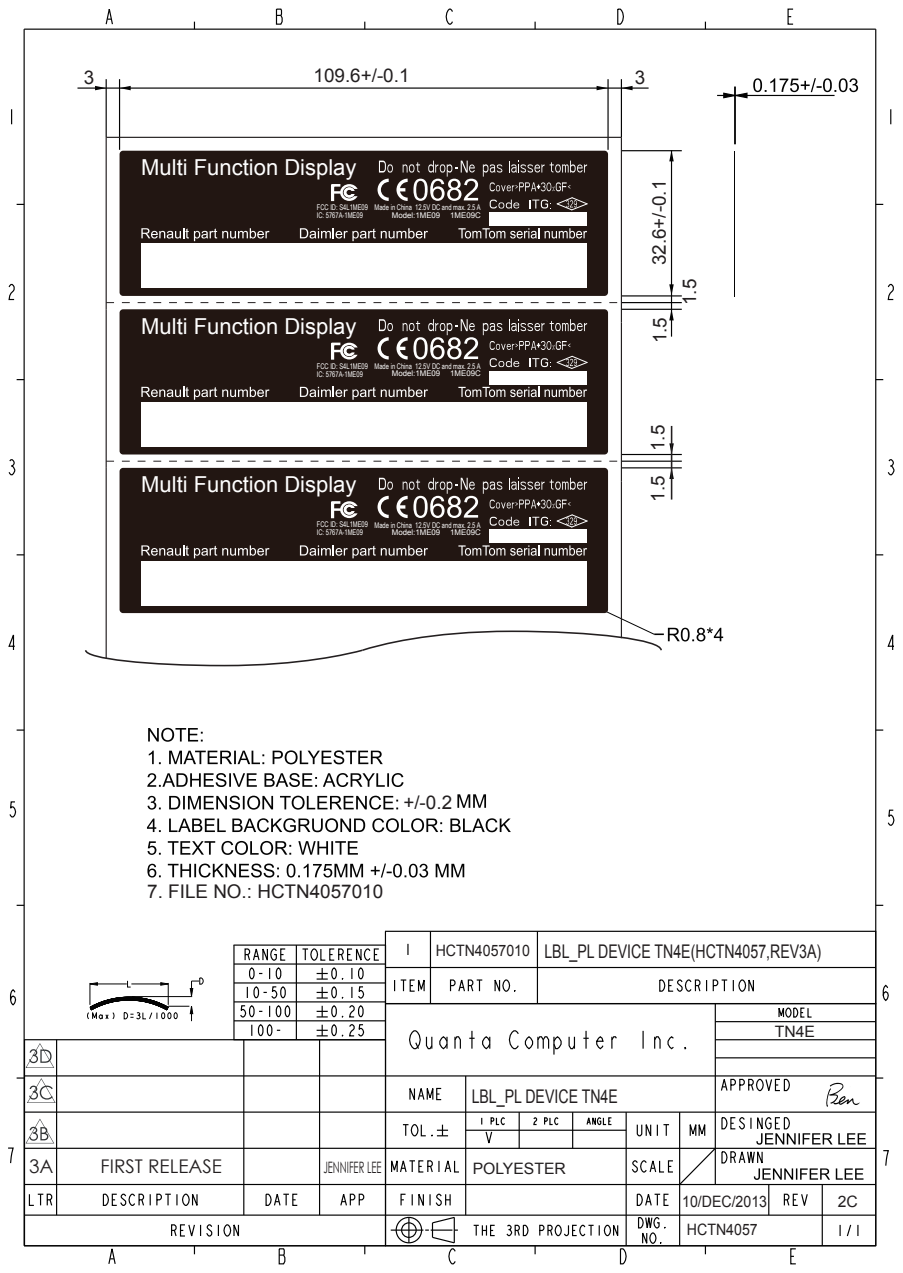
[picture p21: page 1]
HCTN4057010; LBL_PL DEVICE TN4E(HCTN4057,REV3A); LBL_PL DEVICE TN4E; 7. FILE NO.: HCTN4057010; FCC ID: S4L1ME09 IC: 5767A-1ME09

Multi Function Display

Made in China 12.5V DC and max. 2.5 A
Model:1ME09 1ME09C

Model:1ME09

3A | FIRST RELEASE | JENNIFER LEE | POLYESTER

10/DEC/2013 | 2C
HCTN4057

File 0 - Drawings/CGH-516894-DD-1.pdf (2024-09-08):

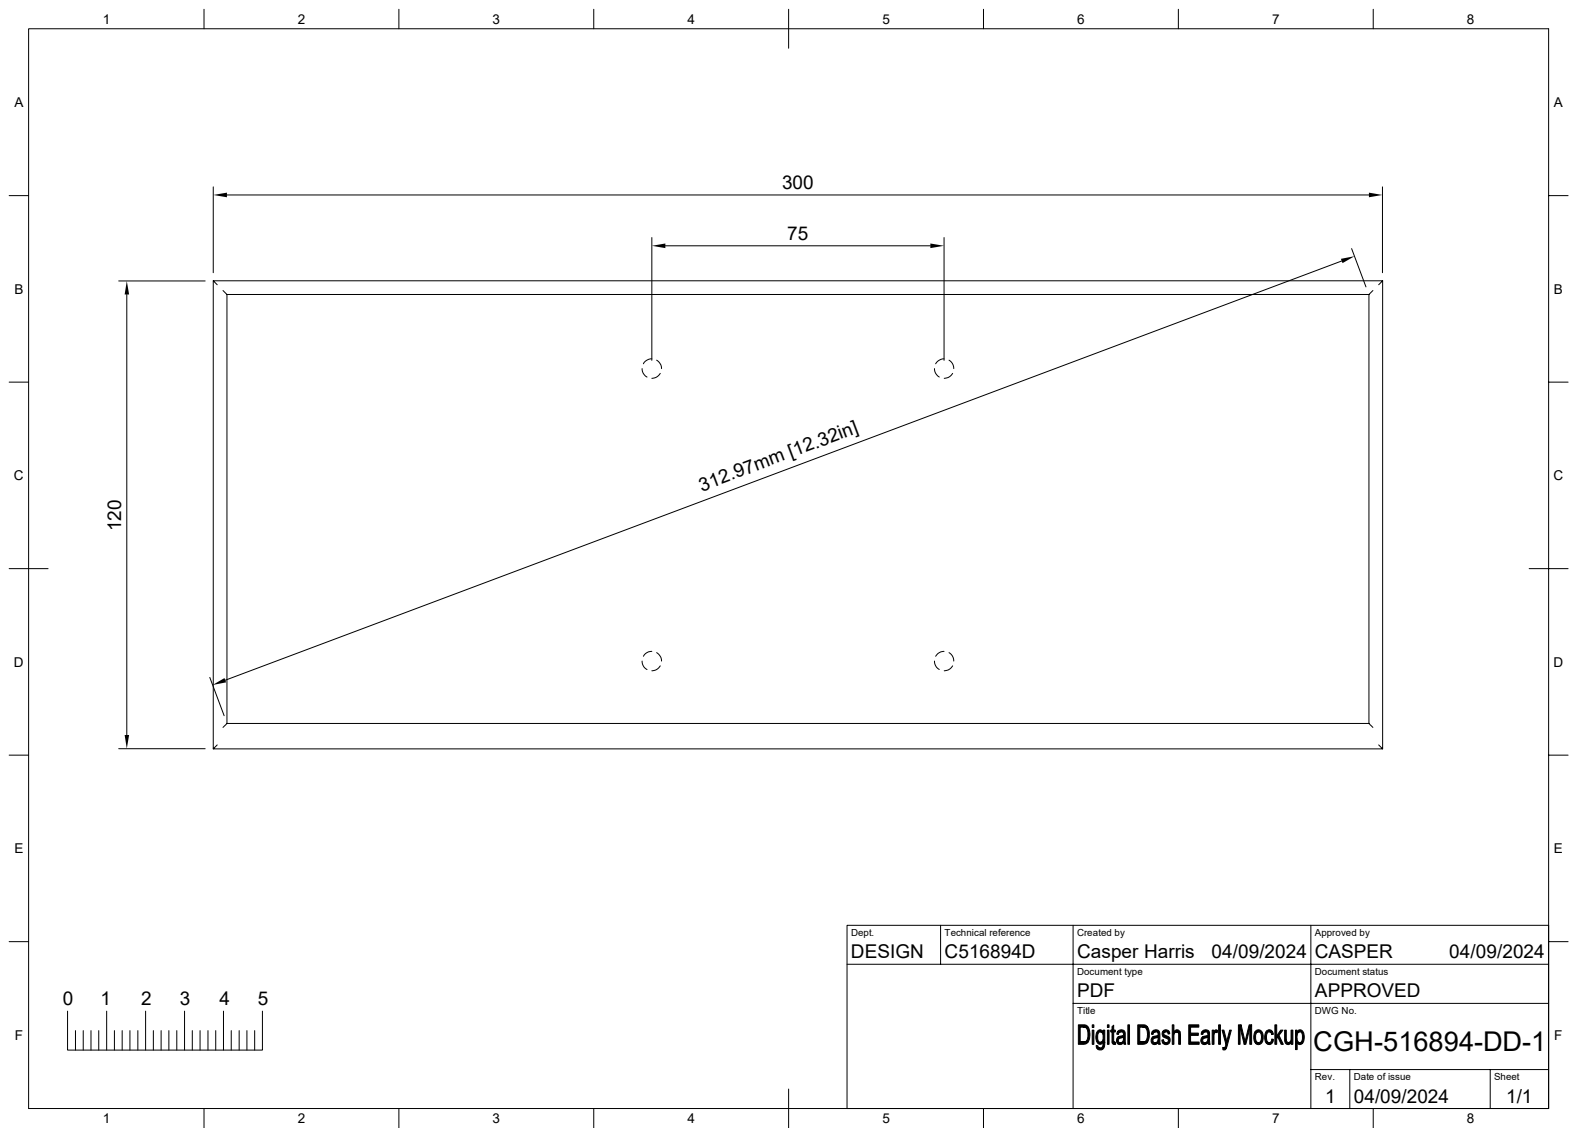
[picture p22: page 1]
8 BCDEF; ABCDEF Dept.; Technical reference; Created by; Approved by Document type; Document status Title; DWG No. Rev.; Date of issue; Sheet 1; 04/09/2024 PDF; APPROVED 04/09/2024; 04/09/2024 1/1 CGH-516894-DD-1 DESIGN; Casper Harris; CASPER 300

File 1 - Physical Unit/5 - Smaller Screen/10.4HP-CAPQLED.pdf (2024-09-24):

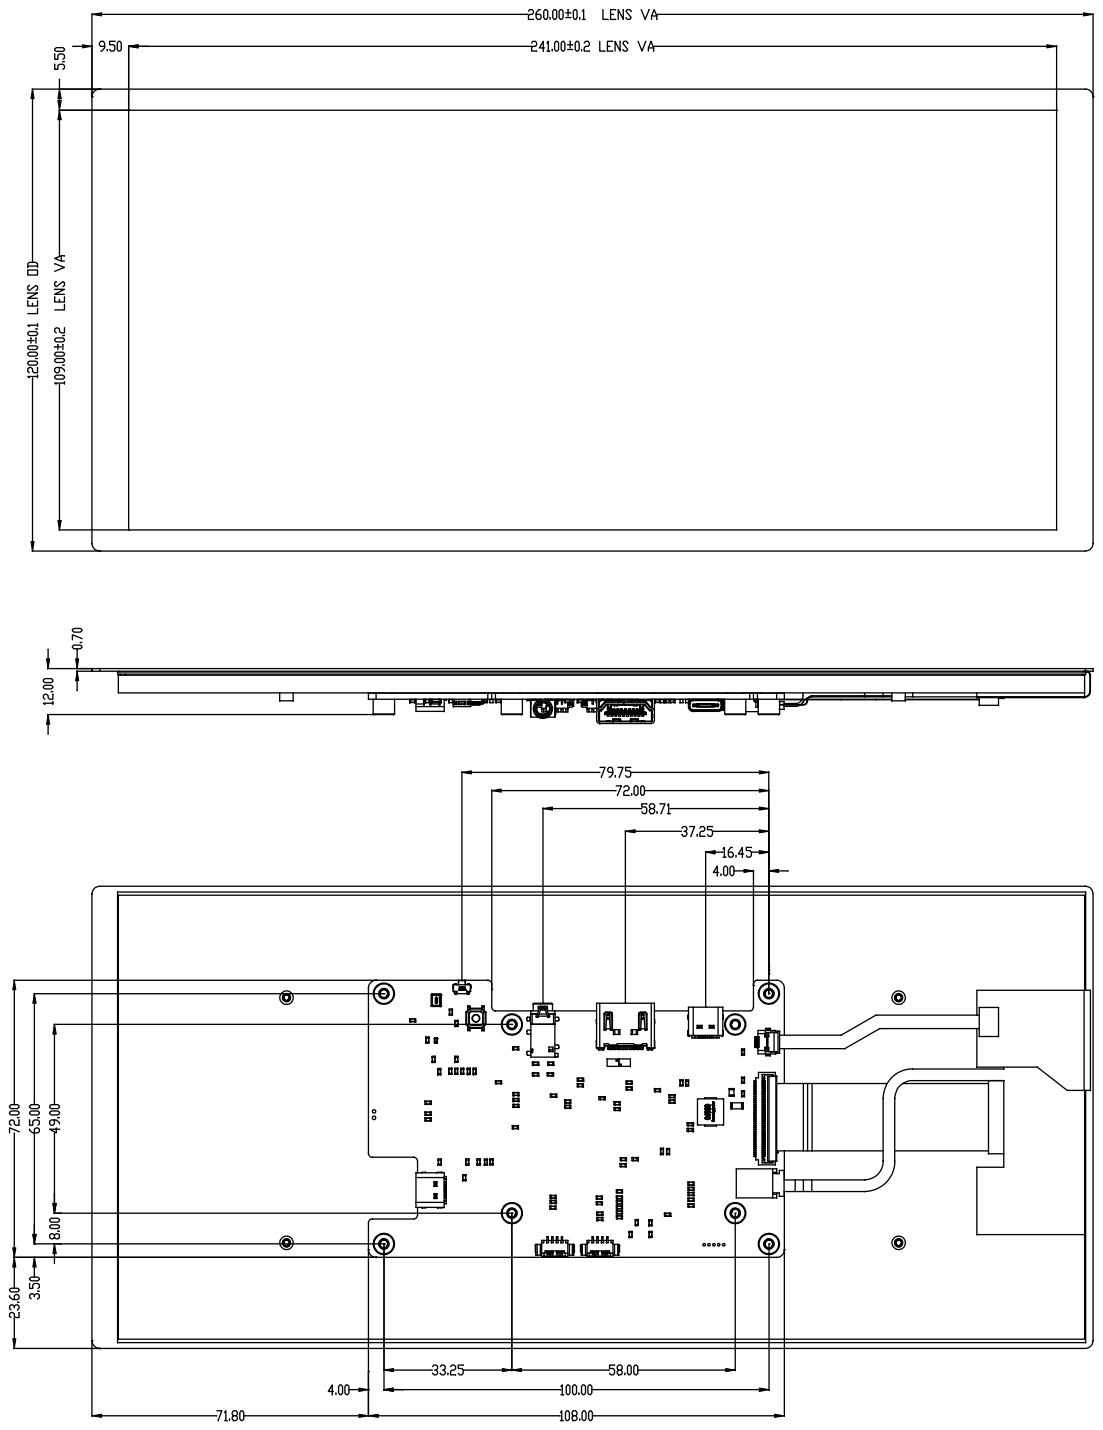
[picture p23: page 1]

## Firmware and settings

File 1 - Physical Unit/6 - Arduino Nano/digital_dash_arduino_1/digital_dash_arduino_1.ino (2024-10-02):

// digital inputs
int stalk_plus = 12;
int stalk_minus = 11;

int oil_pressure = 8;
int brake_fluid = 7;
int handbrake = 4;

// analogue inputs
int fuel_level = A1;
int ext_temp = A2;
int oil_level = A3;

// digital values
unsigned int stalk_plus_ = 0;
unsigned int stalk_minus_ = 0;

unsigned int oil_pressure_ = 0;
unsigned int brake_fluid_ = 0;
unsigned int handbrake_ = 0;

// analogue values
unsigned int ext_temp_  = 0;
unsigned int fuel_level_ = 0;
unsigned int oil_level_ = 0;

unsigned int placeholder = 0;

int output[7] = {0};

void setup()
{
  pinMode(stalk_plus, INPUT_PULLUP);
  pinMode(stalk_minus, INPUT_PULLUP);
  
  pinMode(oil_pressure, INPUT_PULLUP);
  pinMode(brake_fluid, INPUT_PULLUP);
  pinMode(handbrake, INPUT_PULLUP);

  pinMode(fuel_level, INPUT);
  pinMode(ext_temp, INPUT);
  pinMode(oil_pressure, INPUT);

  // init serial
  Serial.begin(115200);
  delay(100);

  Serial.println("Arduino ONLINE");
}

void loop() {
  ReadDigitalStatuses();
  ReadAnalogStatuses();
  SendCANFramesToSerial();
  
  delay(5);
}

void ReadDigitalStatuses() {
  output[0] = digitalRead(handbrake) == HIGH ? 0 : 1;
  output[1] = digitalRead(stalk_plus) == HIGH ? 0 : 1;
  output[2] = digitalRead(stalk_minus) == HIGH ? 0 : 1;
  output[3] = digitalRead(oil_pressure) == HIGH ? 1 : 0;
  output[4] = digitalRead(brake_fluid) == HIGH ? 0 : 1;
}

void ReadAnalogStatuses() {
  fuel_level_ = analogRead(fuel_level);
  ext_temp_ = analogRead(ext_temp);
  oil_level_ = analogRead(oil_level);
}

void SendCANFramesToSerial() {
  byte buf[8];

  // build CAN frame
  memcpy(buf + 0, &ext_temp_, 2);
  memcpy(buf + 2, &fuel_level_, 2);
  memcpy(buf + 4, &output, 1);
  memcpy(buf + 5, &oil_level_, 2)
  memcpy(buf + 7, &placeholder, 1);

  // write CAN frame to serial
  SendCANFrameToSerial(197, buf);
  
  // build CAN frame
  memcpy(buf, &placeholder, 8);

  // write CAN frame to serial
  SendCANFrameToSerial(198, buf);
}

void SendCANFrameToSerial(unsigned long canFrameId, const byte* frameData) {
  // the 4 byte identifier at the beginning of each CAN frame
  // this is required for RealDash to 'catch-up' on ongoing stream of CAN frames
  const byte serialBlockTag[4] = { 0x44, 0x33, 0x22, 0x11 };
  Serial.write(serialBlockTag, 4);

  // the CAN frame id number (as 32bit little endian value)
  Serial.write((const byte*)&canFrameId, 4);

  // CAN frame payload
  Serial.write(frameData, 8);
}

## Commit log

2024-09-08 Main Commit
    [1379681-1.stl, 1379681-1.stp, connector_clamp.stl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]
2024-09-12 Push 2
    [1379681-1.stl, 1379681-1.stp, 16Bit I2C ADC+PGA - ADS1115.stl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]
2024-09-13 Push 3
    [Digital_Dashboard.xlsx, back_cover_left_v1.stl, back_cover_left_v3.stl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]
2024-09-14 Push 4
    [Digital_Dashboard.xlsx]
2024-09-14 Update XML
    [Digital_Dashboard.xlsx]
2024-09-19 Push 5
    [Digital_Dashboard.xlsx, Fluence ZE.xlsx, PR_740_760_11094_GB.xlsx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]
2024-09-19 Push 6
    [Digital_Dashboard.xlsx]
2024-09-19 Push 7
    [Digital_Dashboard.xlsx]
2024-09-20 Pish 7
    [back_cover_left_v3.stl, back_cover_left_v4.stl, back_cover_right_v3.stl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]
2024-09-20 Push 8
    [candump-2024-09-09_005252.xlsm]
2024-09-20 Push 9
    [rdcan_2024-09-08_22-14-06.csv]
2024-09-21 Push 10
    [Digital_Dashboard.xlsx]
2024-09-21 Push 11
    [Digital_Dashboard.xlsx, Fluence ZE.xlsx]
2024-09-21 Update Bavarian Powerhouse-x98_rs.rd
2024-09-21 Push 13
    [Digital_Dashboard.xlsx, candump-2024-09-09_005252.xlsm]
2024-09-21 Push 14
    [Digital_Dashboard.xlsx]
2024-09-21 Push 15
    [Digital_Dashboard.xlsx]
2024-09-24 Push 17
    [CANBUS-Objektverzeichnis.ods, Digital_Dashboard.xlsx, Twizy-SDO-List.ods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]
2024-09-28 Push 18
    [Digital_Dashboard.xlsx, PyRen PID Export.xlsx, bezel_left_v2.stl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]
2024-10-02 Push 20
    [Digital_Dashboard.xlsx, bezel_left_v3.stl, bezel_left_v4.stl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]
2024-10-02 Push 21
    [rdcan_2024-09-29_19-44-44.csv]
2024-10-05 Push 22
    [Digital_Dashboard.xlsx]
